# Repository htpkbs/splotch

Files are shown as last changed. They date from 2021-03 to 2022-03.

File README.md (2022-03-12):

# NB!

The layout of this doesn't work! The row/column hookups to the I/O expander aren't split between the `A` and `B` GPIO ports, so they don't work with the typical custom `matrix.c` that's used for other keyboards that use an I/O expander.

This particular PCB has been effectively abandoned ([see the nikon PCB for a somewhat similar split ergonomic board](https://github.com/htpkbs/nikon)) so this repository will be archived.

# Overview

A split keyboard with a layout inspired by the [Iris](https://keeb.io/products/iris-keyboard-split-ergonomic-keyboard) and through-hole components inspired by the [plaid](https://github.com/hsgw/plaid). It may or may not be easier to find keycap sets that fit this layout with the correct legends (most base GMK sets should work, with the addition of space keys). It also has a rotary encoder on the right half.

# Key Layout

The key layout looks like this (rotary encoder not included). (Thanks to [Keyboard Layout Editor](http://www.keyboard-layout-editor.com/) for the image.)

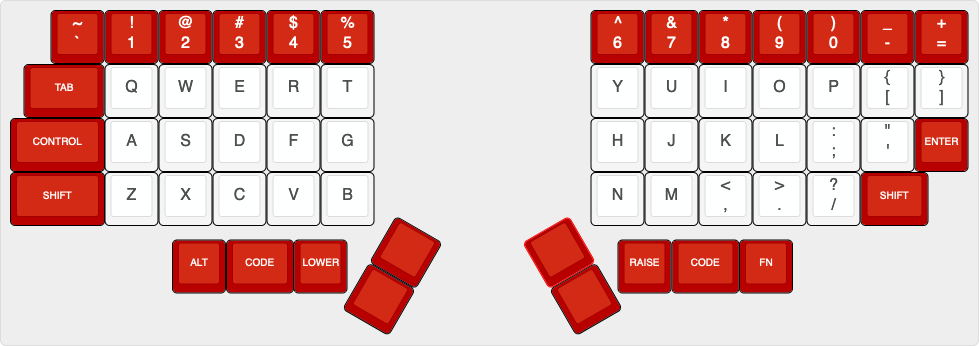
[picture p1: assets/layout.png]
Key layout


This is the corresponding data for pasting into Keyboard Layout Editor:

```
[{x:0.75,c:"#b80000",t:"#f5f5f5",a:5,f:5},"~\n`","!\n1","@\n2","#\n3","$\n4","%\n5",{x:4},"^\n6","&\n7","*\n8","(\n9",")\n0","_\n-","+\n="],
[{x:0.25,a:7,f:2,w:1.5},"TAB",{c:"#f5f5f5",t:"#424242",f:5},"Q","W","E","R","T",{x:4},"Y","U","I","O","P",{a:5},"{\n[","}\n]"],
[{c:"#b80000",t:"#f5f5f5",a:7,f:2,w:1.75},"CONTROL",{c:"#f5f5f5",t:"#424242",f:5},"A","S","D","F","G",{x:4},"H","J","K","L",{a:5},":\n;","\"\n'",{c:"#b80000",t:"#f5f5f5",a:7,f:2},"ENTER"],
[{w:1.75},"SHIFT",{c:"#f5f5f5",t:"#424242",f:5},"Z","X","C","V","B",{x:4},"N","M",{a:5},"<\n,",">\n.","?\n/",{c:"#b80000",t:"#f5f5f5",a:7,f:2,w:1.25},"SHIFT"],
[{y:0.25,x:3},"ALT",{w:1.25},"CODE","LOWER",{x:5},"RAISE",{w:1.25},"CODE","FN"],
[{r:30,rx:6.75,ry:3,y:0.5,x:0.75,f:5},""],
[{x:0.75,f:2},""],
[{r:-30,rx:10.75,y:0.5,x:-1.75,f:5},""],
[{x:-1.75,f:2},""]
```

# PCB Renders

## Left

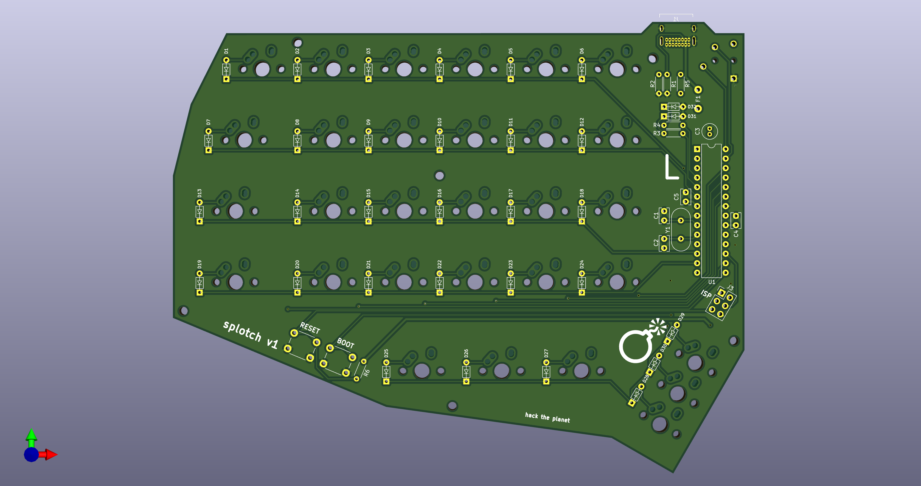
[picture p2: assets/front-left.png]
Left PCB front


## Right

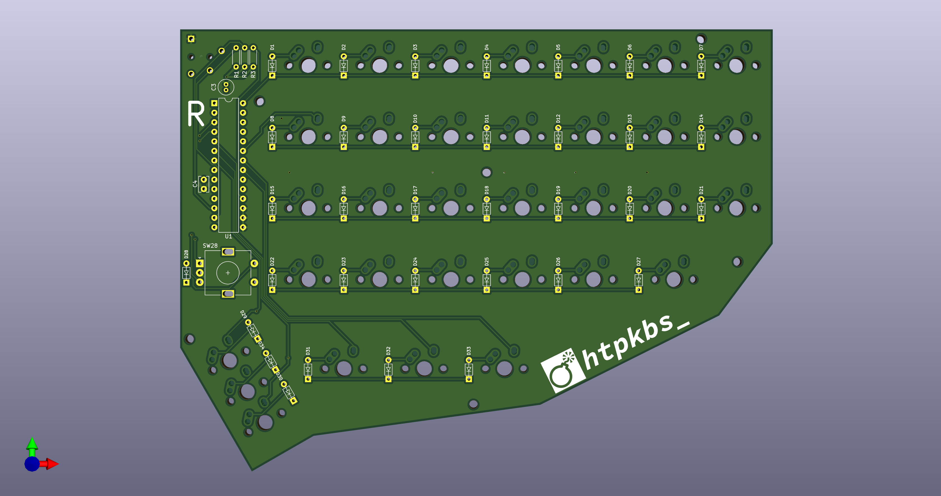
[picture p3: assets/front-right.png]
Right PCB front


# Case/Back Plates

There are no plate or full case files (sandwich style is hard with exposed components...) but there are some DXF files to print back plates for each half. You can mount the PCBs to these back plates using M2 size screws and standoffs. [Here is the file for the left back plate](assets/case-left.dxf) and [here is the file for the right back plate](assets/case-right.dxf).

# Schematic

There is a PDF of the [schematic of the left half here](assets/schematic-left.pdf) and the [schematic of the right half here](assets/schematic-right.pdf). There is a [bill of materials (BOM) here](BOM.md).

# AVR Notes

There will be some notes about programming the microcontroller with [USBaspLoader](https://github.com/baerwolf/USBaspLoader) here. [The ATmega328P datasheet is here](https://ww1.microchip.com/downloads/en/DeviceDoc/Atmel-7810-Automotive-Microcontrollers-ATmega328P_Datasheet.pdf) and [the MC32017 datasheet is here](https://ww1.microchip.com/downloads/en/devicedoc/20001952c.pdf). The keyboard does not use QMK's split keyboard functionality, but extends the number of available I/O pins by communicating with I2C over the TRRS cable. This means it should appear as a single, non-split keyboard to QMK, and has the benefit of requiring fewer components on the right half of the keyboard.

# Sublicenses

* Thank you to [coseyfannitutti](https://github.com/coseyfannitutti) for the footprints `D_DO-35_SOD27_P5.08mm_Horizontal.kicad_mod` and `USB_C_GCT_USB4085.kicad_mod`. [The Creative Commons license for these is included here](LICENSE.CFTKB).
* Thanks to [ai03-2725](https://github.com/ai03-2725) for the `MX*` symbols. [The MIT license for these is included here](LICENSE.ai03).

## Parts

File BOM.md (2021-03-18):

# Bill of Materials (BOM)

## Left PCB

SW1-SW30 (keyswitches) and H1-H6 (mounting holes) are not included.

| Reference | Quantity | Value | Manufacturer | Manufacturer Part No. | DigiKey Link |
| --- | --- | --- | --- | --- | --- |
| C1, C2 | 2 | 22pF | Vishay BC Components | K220J15C0GH53L2 | https://www.digikey.com/product-detail/en/vishay-bc-components/K220J15C0GH53L2/BC5147-ND/2821627 |
| C3 | 1 | 4.7u | Panasonic Electronic Components | ECE-A1HKA4R7 | https://www.digikey.com/product-detail/en/panasonic-electronic-components/ECE-A1HKA4R7/P827-ND/6934 |
| C4, C5 | 2 | 0.1u | Vishay BC Components | K104Z15Y5VF5TL2 | https://www.digikey.com/product-detail/en/vishay-bc-components/K104Z15Y5VF5TL2/BC1160CT-ND/286782 |
| D1-D30 | 30 | 1N4148 | Vishay Semiconductor Diodes Division | TZX3V6B-TR | https://www.digikey.com/product-detail/en/vishay-semiconductor-diodes-division/TZX3V6B-TR/TZX3V6B-TRGICT-ND/9601328 |
| D31, D32 | 2 | 3.6V | Vishay Semiconductor Diodes Division | 1N4148TR | https://www.digikey.com/product-detail/en/vishay-semiconductor-diodes-division/1N4148TR/1N4148VSCT-ND/3104297 |
| F1 | 1 | 100mA | Bourns Inc. | MF-R010 |https://www.digikey.com/product-detail/en/bourns-inc/MF-R010/MF-R010-ND/259959 |
| J1 | 1 | USB_C_Receptacle_USB2.0 | GCT | USB4085-GF-A | https://www.digikey.com/product-detail/en/USB4085-GF-A/2073-USB4085-GF-ACT-ND/9859733 |
| J2 | 1 | SJ-43514 | CUI Devices | SJ-43514 | https://www.digikey.com/product-detail/en/cui-inc/SJ-43514/CP-43514-ND/368146 |
| J3 | 1 | AVR-ISP-6 | METZ CONNECT USA Inc. | PR20203VBDN | https://www.digikey.com/product-detail/en/metz-connect-usa-inc/PR20203VBDN/1849-PR20203VBDN-ND/12342894 |
| R1, R2 | 2 | 5.1k | Vishay BC Components | MBA02040C5101FCT00 | https://www.digikey.com/product-detail/en/vishay-bc-components/MBA02040C5101FCT00/BC3294CT-ND/6138797 |
| R3, R4 | 2 | 75R | Vishay BC Components | SFR16S0007509FR500 | https://www.digikey.com/product-detail/en/vishay-bc-components/SFR16S0007509FR500/PPC75-0XCT-ND/594880 |
| R5 | 1 | 1.5k | Vishay BC Components | SFR16S0001501JA500 | https://www.digikey.com/product-detail/en/vishay-bc-components/SFR16S0001501JA500/BC4304CT-ND/7351734 |
| R6 | 1 | 10k | Vishay BC Components | SFR16S0001002JA500 | https://www.digikey.com/product-detail/en/vishay-bc-components/SFR16S0001002JA500/BC4294CT-ND/7351724 |
| R7, R8 | 2 | 4.7k | Vishay BC Components | MBA02040C5101FCT00 | https://www.digikey.com/product-detail/en/vishay-bc-components/MBA02040C4701FCT00/BC3275CT-ND/6138778 |
| SW31 | 1 | Reset | TE Connectivity ALCOSWITCH Switches | 1825910-3 | https://www.digikey.com/product-detail/en/te-connectivity-alcoswitch-switches/1825910-3/450-3354-ND/2400476 |
| SW32 | 1 | Boot | TE Connectivity ALCOSWITCH Switches | 1825910-2 | https://www.digikey.com/product-detail/en/te-connectivity-alcoswitch-switches/1825910-2/450-1649-ND/1632535 |
| U1 | 1 | ATmega328P-PU | Microchip Technology | ATMEGA328P-PU | https://www.digikey.com/product-detail/en/microchip-technology/ATMEGA328P-PU/ATMEGA328P-PU-ND/1914589 |
| U1 (socket) | 1 | DIP Socket | Mill-Max Manufacturing Corp. | 115-43-328-41-001000 | https://www.digikey.com/product-detail/en/mill-max-manufacturing-corp/115-43-328-41-001000/ED90203-ND/1212100 |
| Y1 | 1 | 16MHz | Abracon LLC | ABL-16.000MHZ-B2 | https://www.digikey.com/product-detail/en/abracon-llc/ABL-16-000MHZ-B2/535-9041-ND/675236 |

## Right PCB

SW1-SW27, SW29-34 (keyswitches) and H1-H6 (mounting holes) are not included.

| Reference | Quantity | Value | Manufacturer | Manufacturer Part No. | DigiKey Link |
| --- | --- | --- | --- | --- | --- |
| C3 | 1 | 4.7u | Panasonic Electronic Components | ECE-A1HKA4R7 | https://www.digikey.com/product-detail/en/panasonic-electronic-components/ECE-A1HKA4R7/P827-ND/6934 |
| C4 | 1 | 0.1u | Vishay BC Components | K104Z15Y5VF5TL2 | https://www.digikey.com/product-detail/en/vishay-bc-components/K104Z15Y5VF5TL2/BC1160CT-ND/286782 |
| D1-D34 | 34 | 1N4148 | Vishay Semiconductor Diodes Division | TZX3V6B-TR | https://www.digikey.com/product-detail/en/vishay-semiconductor-diodes-division/TZX3V6B-TR/TZX3V6B-TRGICT-ND/9601328 |
| J2 | 1 | SJ-43514 | CUI Devices | SJ-43514 | https://www.digikey.com/product-detail/en/cui-inc/SJ-43514/CP-43514-ND/368146 |
| R1, R2 | 2 | 4.7k | Vishay BC Components | MBA02040C5101FCT00 | https://www.digikey.com/product-detail/en/vishay-bc-components/MBA02040C4701FCT00/BC3275CT-ND/6138778 |
| R3 | 1 | 10k | Vishay BC Components | SFR16S0001002JA500 | https://www.digikey.com/product-detail/en/vishay-bc-components/SFR16S0001002JA500/BC4294CT-ND/7351724 |
| SW28 | 1 | EC11 | Alps Alpine | EC11E152U402 | https://www.mouser.com/ProductDetail/Alps-Alpine/EC11E152U402?qs=ZH26iPUykMVNjOPdkrJGwQ%3D%3D (these aren't on Digikey for some reason; any EC11 style encoder should work) |
| SW31 | 1 | Reset | TE Connectivity ALCOSWITCH Switches | 1825910-3 | https://www.digikey.com/product-detail/en/te-connectivity-alcoswitch-switches/1825910-3/450-3354-ND/2400476 |
| SW32 | 1 | Boot | TE Connectivity ALCOSWITCH Switches | 1825910-2 | https://www.digikey.com/product-detail/en/te-connectivity-alcoswitch-switches/1825910-2/450-1649-ND/1632535 |
| U1 | 1 | MCP23017 | Microchip Technology | MCP23017-E/SP | https://www.digikey.com/en/products/detail/microchip-technology/MCP23017-E-SP/894272 |
| U1 (socket) | 1 | DIP Socket | Mill-Max Manufacturing Corp. | 115-43-328-41-001000 | https://www.digikey.com/product-detail/en/mill-max-manufacturing-corp/115-43-328-41-001000/ED90203-ND/1212100 |

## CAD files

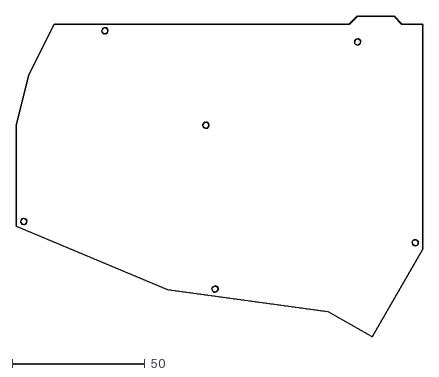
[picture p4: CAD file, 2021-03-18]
assets/case-left.dxf
152.7 x 120.6

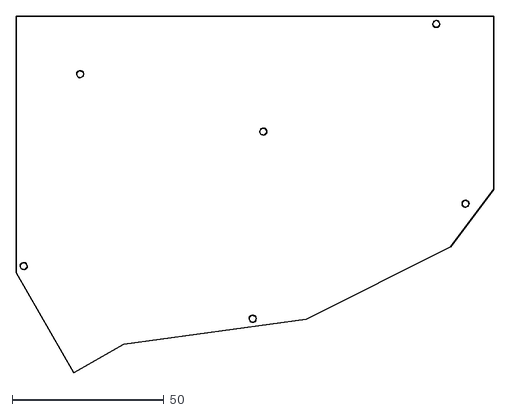
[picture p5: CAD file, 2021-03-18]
assets/case-right.dxf
157.5 x 117.5

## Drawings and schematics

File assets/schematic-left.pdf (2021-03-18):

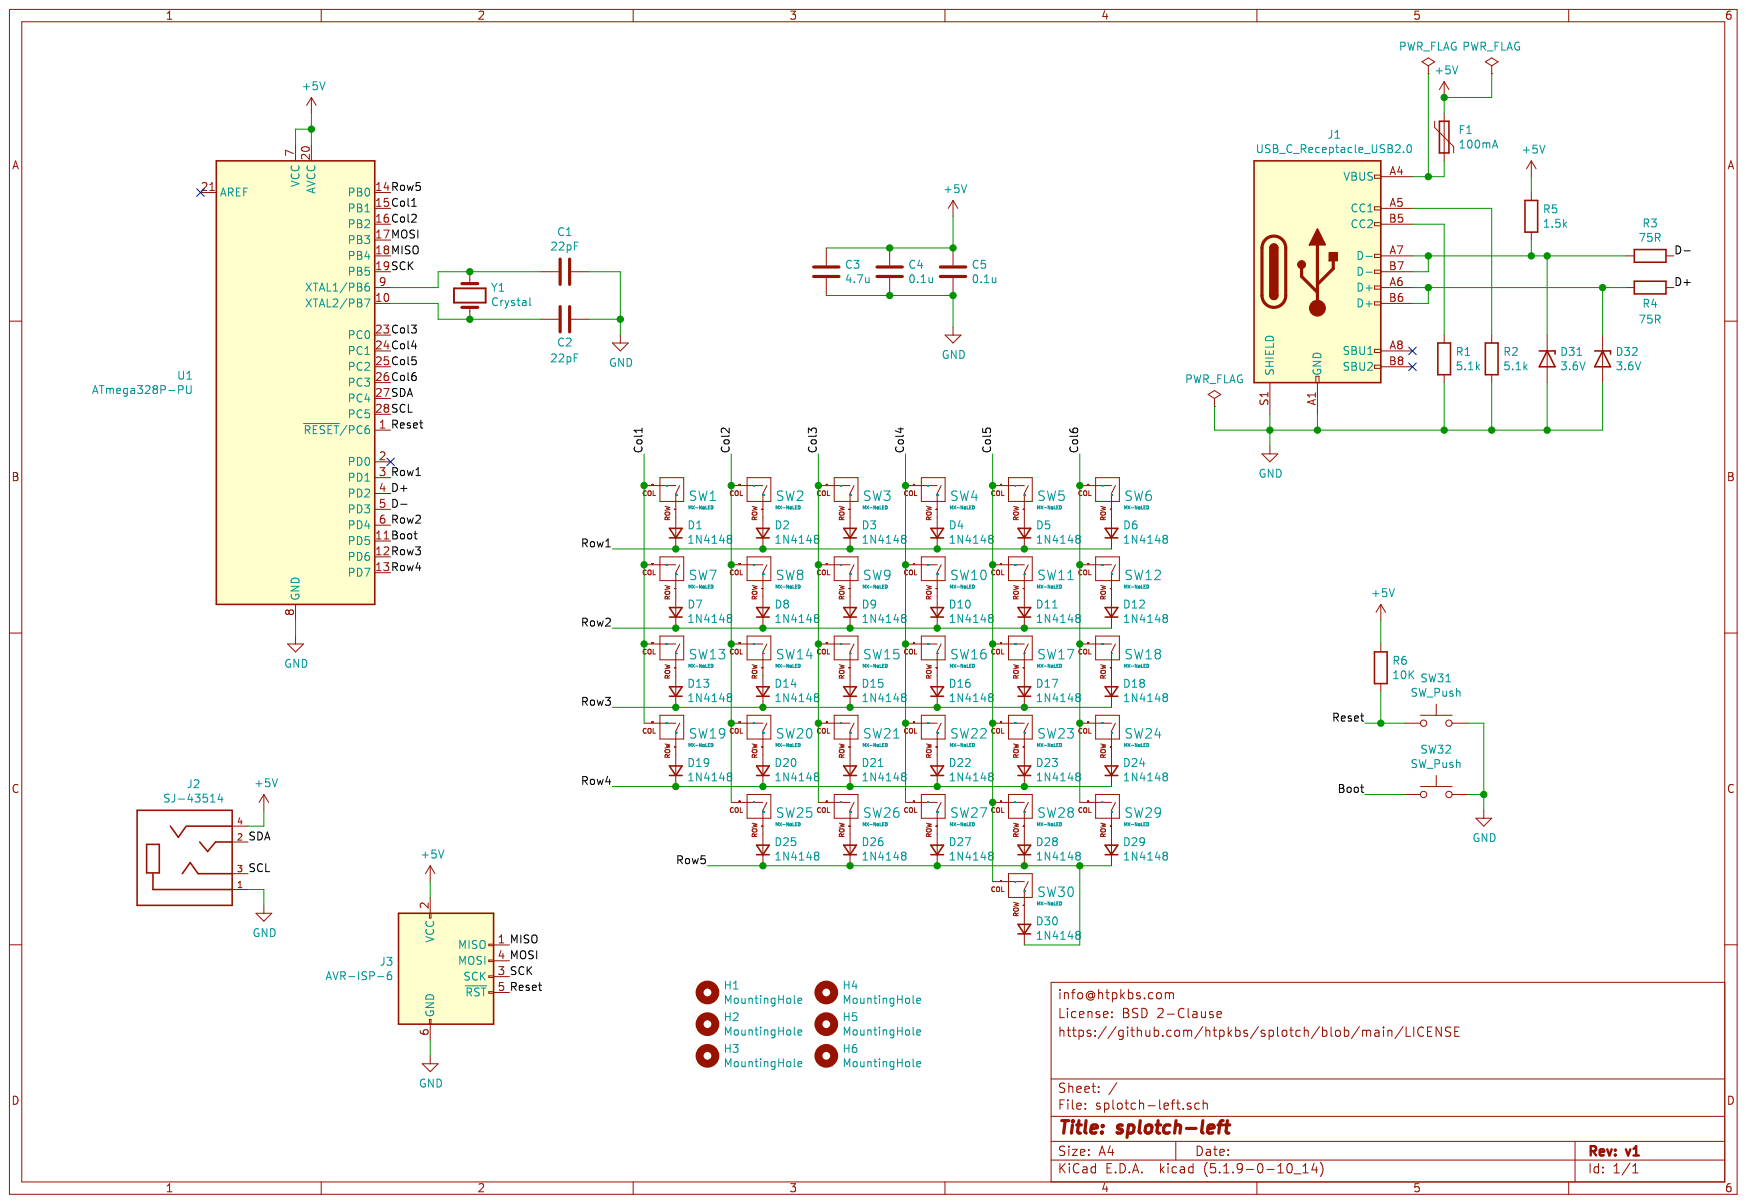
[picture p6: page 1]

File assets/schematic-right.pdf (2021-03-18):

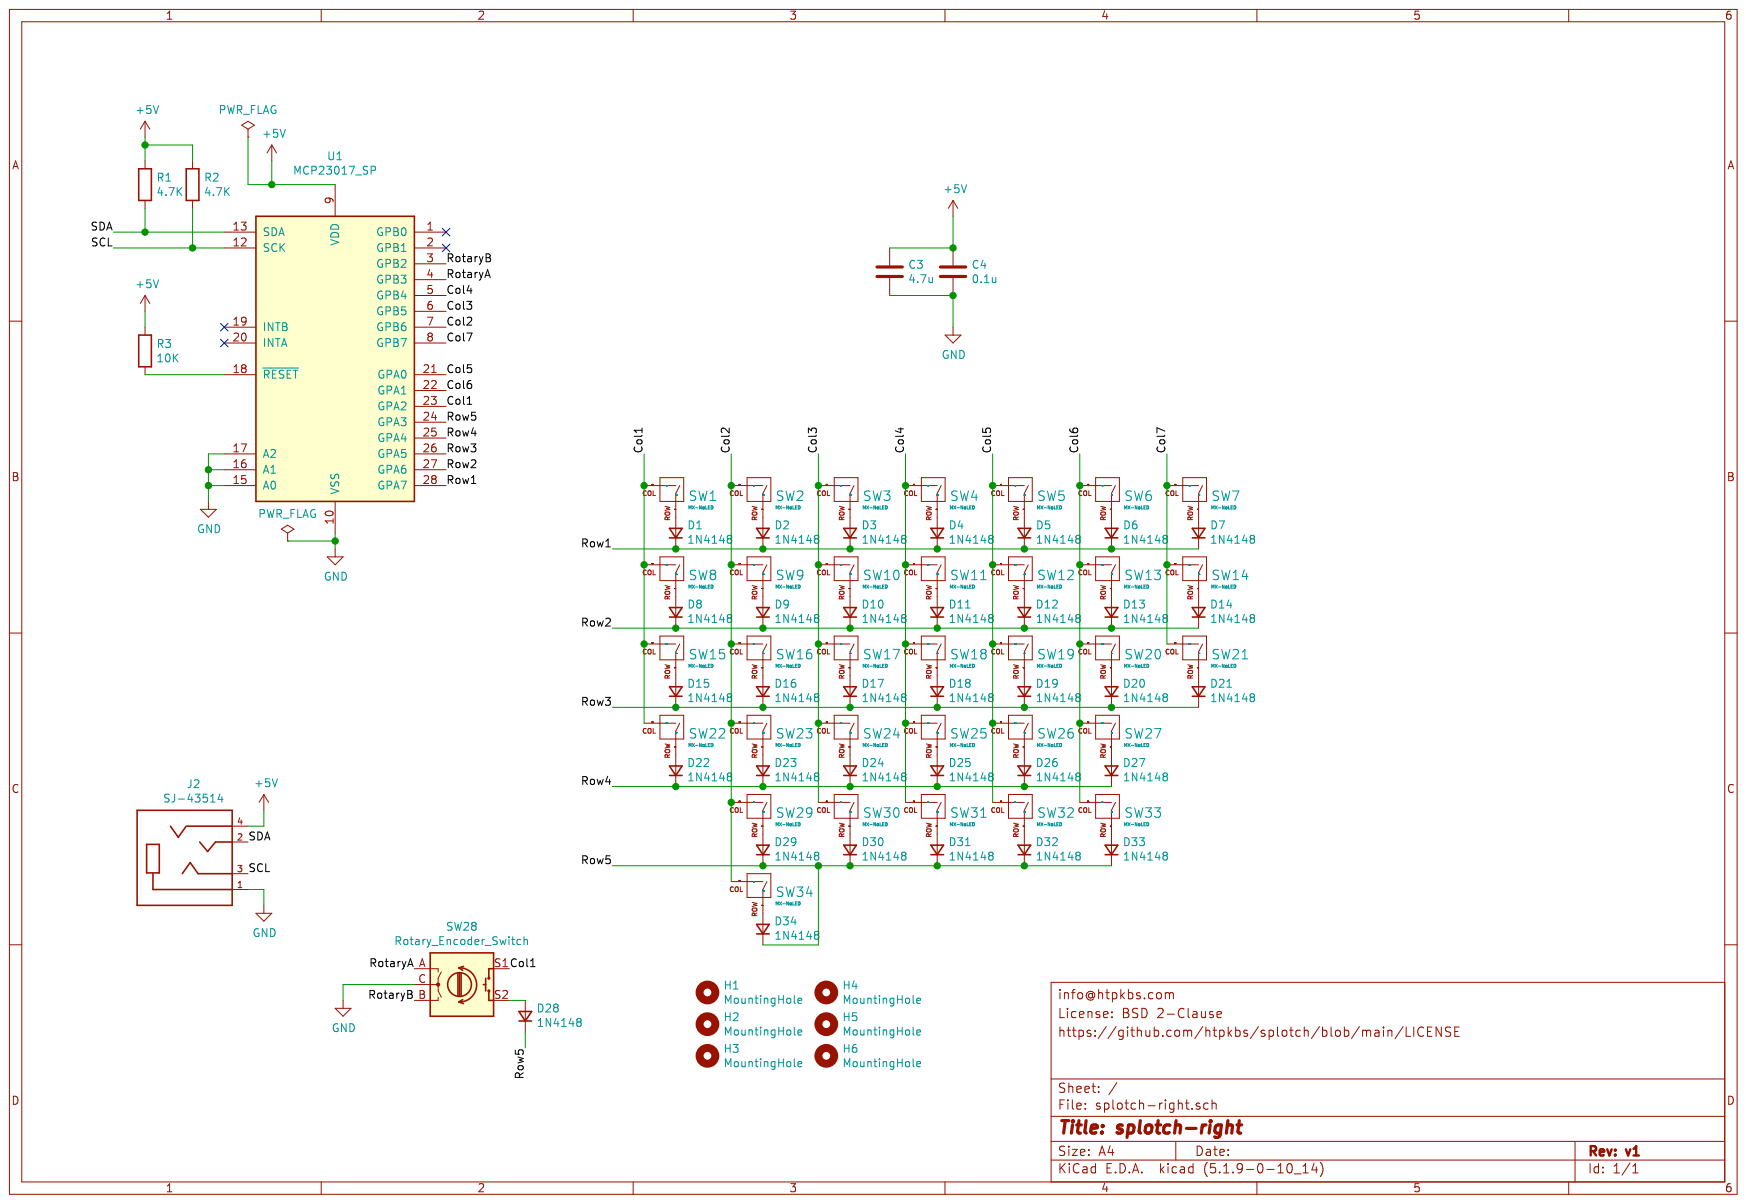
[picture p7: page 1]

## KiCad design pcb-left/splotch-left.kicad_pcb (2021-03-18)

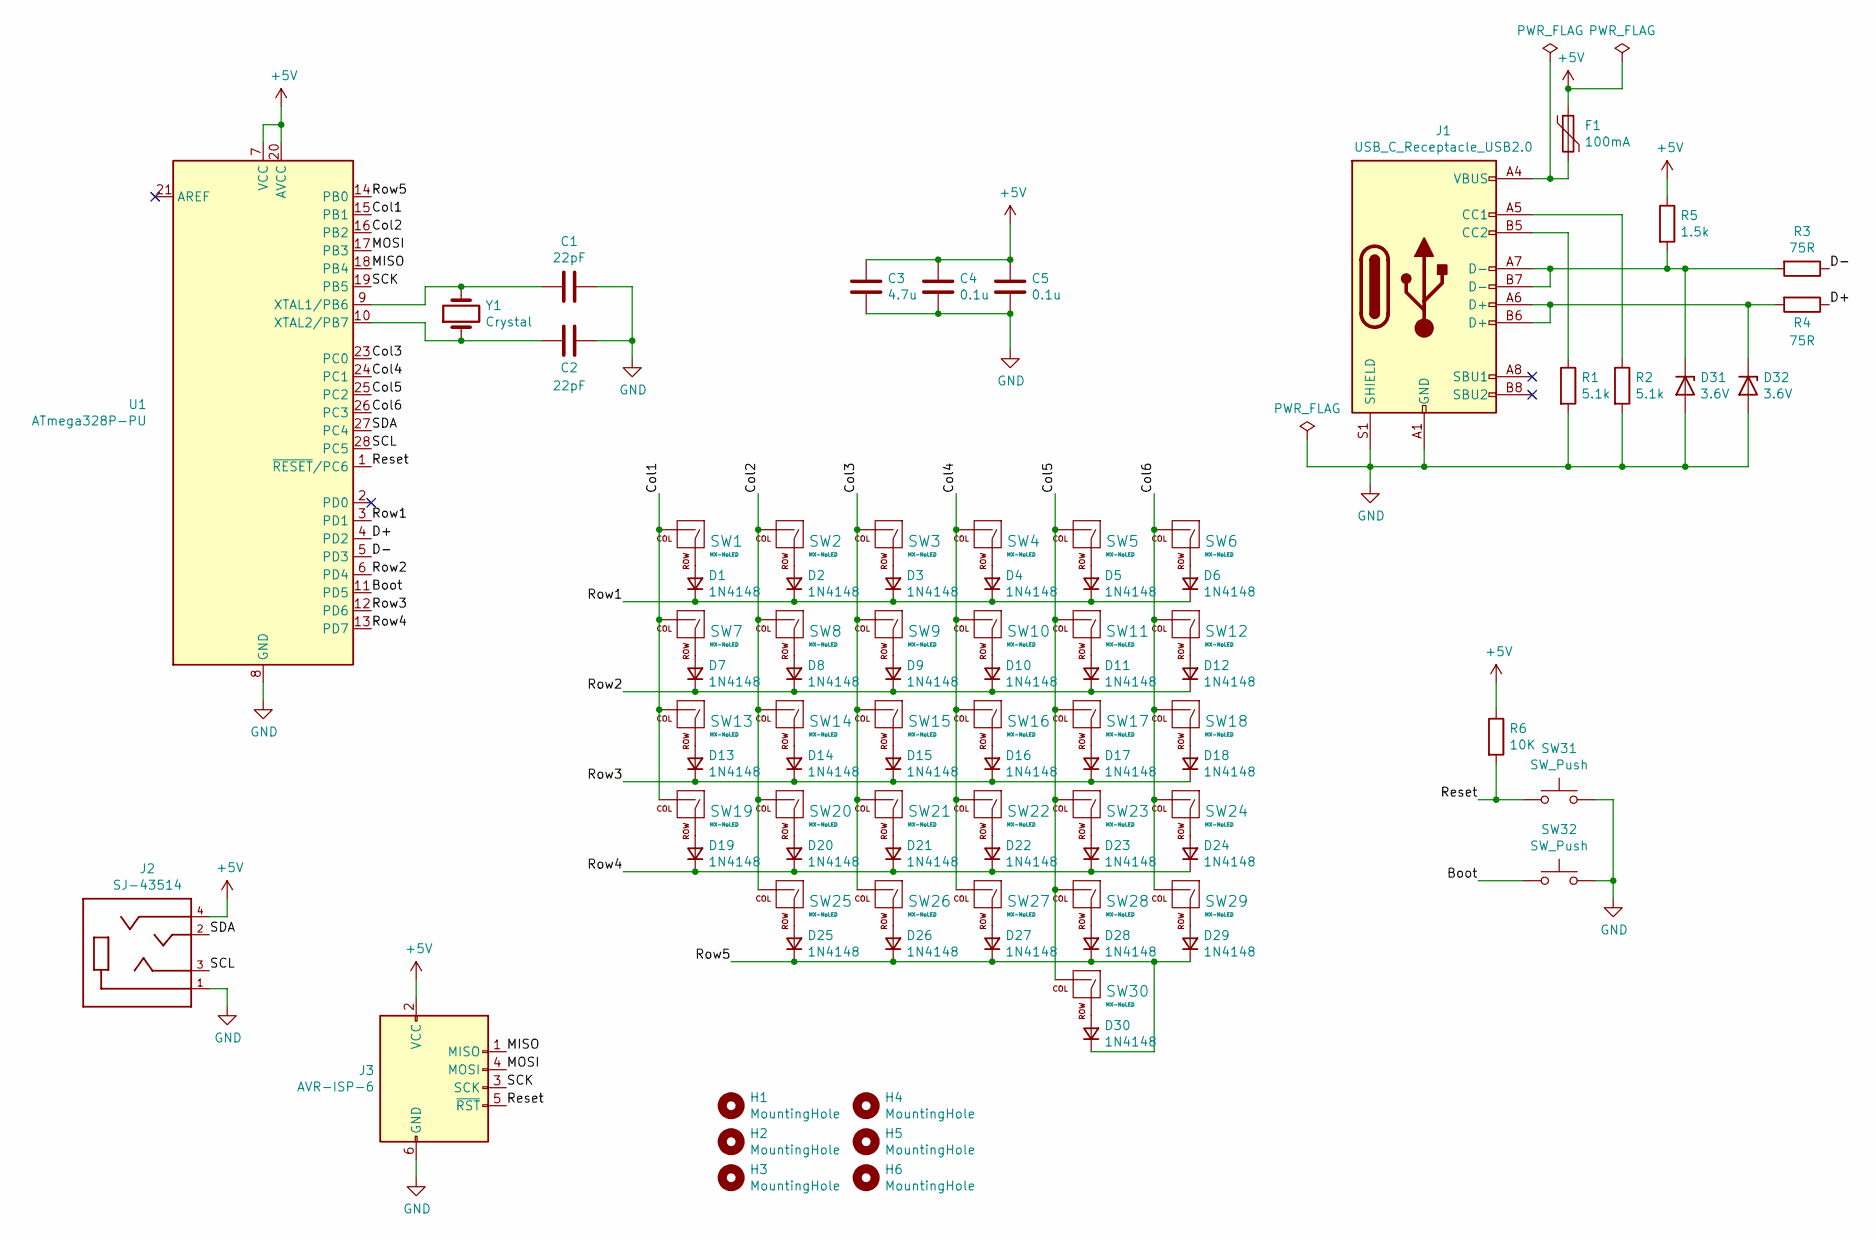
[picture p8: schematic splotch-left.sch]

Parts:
C1, C2: 22pF; C_Rect_L4.0mm_W2.5mm_P2.50mm
C3: 4.7u; C_Radial_D4.0mm_H7.0mm_P1.50mm
C4, C5: 0.1u; C_Rect_L4.0mm_W2.5mm_P2.50mm
D1, D2, D3, D4, D5, D6, D7, D8, D9, D10, D11, D12, D13, D14, D15, D16, D17, D18, D19, D20, D21, D22, D23, D24, D25, D26, D27, D28, D29, D30: 1N4148; D_DO-35_SOD27_P5.08mm_Horizontal
D31, D32: 3.6V; D_DO-35_SOD27_P5.08mm_Horizontal
F1: 100mA; Fuse_Littelfuse_395Series
H1, H2, H3, H4, H5, H6: MountingHole; MountingHole_2.2mm_M2
J1: USB_C_Receptacle_USB2.0; USB_C_GCT_USB4085
J2: SJ-43514; CUI_SJ-43514
J3: AVR-ISP-6; PinHeader_2x03_P2.54mm_Vertical
R1, R2: 5.1k; R_Axial_DIN0204_L3.6mm_D1.6mm_P5.08mm_Horizontal
R3, R4: 75R; R_Axial_DIN0204_L3.6mm_D1.6mm_P5.08mm_Horizontal
R5: 1.5k; R_Axial_DIN0204_L3.6mm_D1.6mm_P5.08mm_Horizontal
R6: 10K; R_Axial_DIN0204_L3.6mm_D1.6mm_P5.08mm_Horizontal
SW1, SW2, SW3, SW4, SW5, SW6, SW8, SW9, SW10, SW11, SW12, SW14, SW15, SW16, SW17, SW18, SW20, SW21, SW22, SW23, SW24, SW25, SW27, SW28, SW29, SW30: MX-NoLED; MX-1U-NoLED
SW7: MX-NoLED; MX-1.5U-NoLED
SW13, SW19: MX-NoLED; MX-1.75U-NoLED
SW26: MX-NoLED; MX-1.25U-NoLED
SW31, SW32: SW_Push; SW_PUSH_6mm_H4.3mm
U1: ATmega328P-PU; DIP-28_W7.62mm
Y1: Crystal; Crystal_HC49-4H_Vertical

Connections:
+5V: C3.1, C4.1, C5.1, F1.1, J2.4, J3.2 (VCC), R5.1, R6.1, U1.7 (VCC), U1.20 (AVCC)
/Boot: SW32.1, U1.11 (PD5)
/Col1: SW1.2 (ROW), SW7.2 (ROW), SW13.2 (ROW), SW19.2 (ROW), U1.15 (PB1)
/Col2: SW2.2 (ROW), SW8.2 (ROW), SW14.2 (ROW), SW20.2 (ROW), SW25.2 (ROW), U1.16 (PB2)
/Col3: SW3.2 (ROW), SW9.2 (ROW), SW15.2 (ROW), SW21.2 (ROW), SW26.2 (ROW), U1.23 (PC0)
/Col4: SW4.2 (ROW), SW10.2 (ROW), SW16.2 (ROW), SW22.2 (ROW), SW27.2 (ROW), U1.24 (PC1)
/Col5: SW5.2 (ROW), SW11.2 (ROW), SW17.2 (ROW), SW23.2 (ROW), SW28.2 (ROW), SW30.2 (ROW), U1.25 (PC2)
/Col6: SW6.2 (ROW), SW12.2 (ROW), SW18.2 (ROW), SW24.2 (ROW), SW29.2 (ROW), U1.26 (PC3)
/D+: R4.1, U1.4 (PD2)
/D-: R3.1, U1.5 (PD3)
/MISO: J3.1 (MISO), U1.18 (PB4)
/MOSI: J3.4 (MOSI), U1.17 (PB3)
/Reset: J3.5 (~RST), R6.2, SW31.1, U1.1 (~RESET~/PC6)
/Row1: D1.1 (K), D2.1 (K), D3.1 (K), D4.1 (K), D5.1 (K), D6.1 (K), U1.3 (PD1)
/Row2: D7.1 (K), D8.1 (K), D9.1 (K), D10.1 (K), D11.1 (K), D12.1 (K), U1.6 (PD4)
/Row3: D13.1 (K), D14.1 (K), D15.1 (K), D16.1 (K), D17.1 (K), D18.1 (K), U1.12 (PD6)
/Row4: D19.1 (K), D20.1 (K), D21.1 (K), D22.1 (K), D23.1 (K), D24.1 (K), U1.13 (PD7)
/Row5: D25.1 (K), D26.1 (K), D27.1 (K), D28.1 (K), D29.1 (K), D30.1 (K), U1.14 (PB0)
/SCK: J3.3 (SCK), U1.19 (PB5)
/SCL: J2.3, U1.28 (PC5)
/SDA: J2.2, U1.27 (PC4)
GND: C1.1, C2.2, C3.2, C4.2, C5.2, D31.2 (A), D32.2 (A), J1.A1 (GND), J1.A12 (GND), J1.B1 (GND), J1.B12 (GND), J1.S1 (SHIELD), J2.1, J3.6 (GND), R1.2, R2.2, SW31.2, SW32.2, U1.8 (GND), U1.22 (GND)
unnamed: C1.2, U1.9 (XTAL1/PB6), Y1.2
unnamed: C2.1, U1.10 (XTAL2/PB7), Y1.1
unnamed: D1.2 (A), SW1.1 (COL)
unnamed: D2.2 (A), SW2.1 (COL)
unnamed: D3.2 (A), SW3.1 (COL)
unnamed: D4.2 (A), SW4.1 (COL)
unnamed: D5.2 (A), SW5.1 (COL)
unnamed: D6.2 (A), SW6.1 (COL)
unnamed: D7.2 (A), SW7.1 (COL)
unnamed: D8.2 (A), SW8.1 (COL)
unnamed: D9.2 (A), SW9.1 (COL)
unnamed: D10.2 (A), SW10.1 (COL)
unnamed: D11.2 (A), SW11.1 (COL)
unnamed: D12.2 (A), SW12.1 (COL)
unnamed: D13.2 (A), SW13.1 (COL)
unnamed: D14.2 (A), SW14.1 (COL)
unnamed: D15.2 (A), SW15.1 (COL)
unnamed: D16.2 (A), SW16.1 (COL)
unnamed: D17.2 (A), SW17.1 (COL)
unnamed: D18.2 (A), SW18.1 (COL)
unnamed: D19.2 (A), SW19.1 (COL)
unnamed: D20.2 (A), SW20.1 (COL)
unnamed: D21.2 (A), SW21.1 (COL)
unnamed: D22.2 (A), SW22.1 (COL)
unnamed: D23.2 (A), SW23.1 (COL)
unnamed: D24.2 (A), SW24.1 (COL)
unnamed: D25.2 (A), SW25.1 (COL)
unnamed: D26.2 (A), SW26.1 (COL)
unnamed: D27.2 (A), SW27.1 (COL)
unnamed: D28.2 (A), SW28.1 (COL)
unnamed: D29.2 (A), SW29.1 (COL)
unnamed: D30.2 (A), SW30.1 (COL)
unnamed: D31.1 (K), J1.A7 (D-), J1.B7 (D-), R3.2, R5.2
unnamed: D32.1 (K), J1.A6 (D+), J1.B6 (D+), R4.2
unnamed: F1.2, J1.A4 (VBUS), J1.A9 (VBUS), J1.B4 (VBUS), J1.B9 (VBUS)
unnamed: J1.A5 (CC1), R2.1
unnamed: J1.B5 (CC2), R1.1

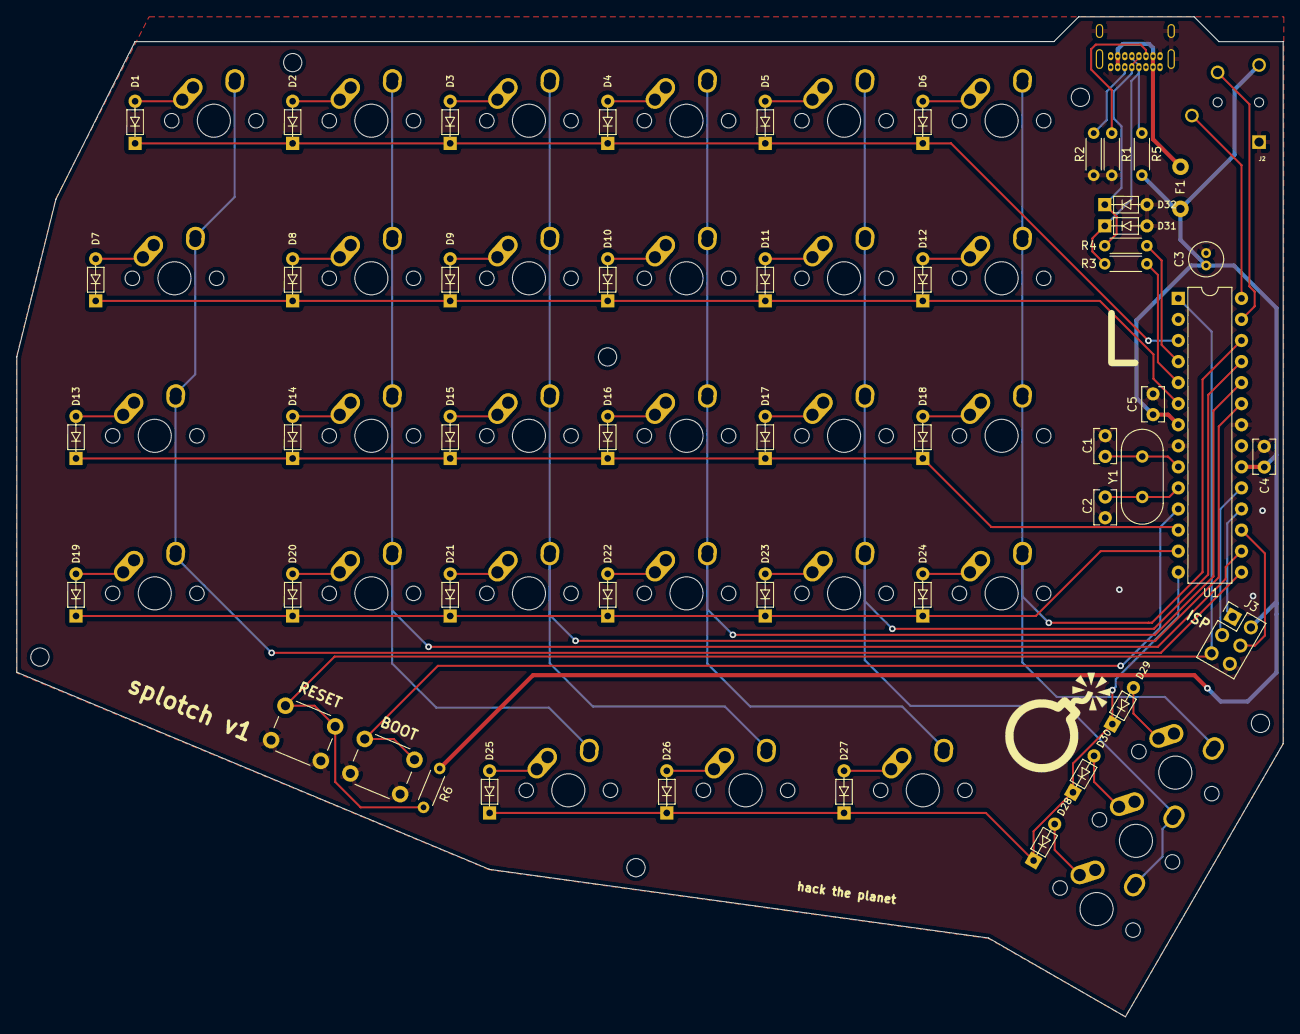
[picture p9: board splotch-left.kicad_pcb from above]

Board: 2 copper layers, 152.7 x 120.6 mm, 87 parts (1 on the bottom side), 59 nets.

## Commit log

2021-03-18 Add back plate/case files
    [case-left.dxf, case-right.dxf]
2021-03-18 updated pcb renders
2021-03-18 add BOM

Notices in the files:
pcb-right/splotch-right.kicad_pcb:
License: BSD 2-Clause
